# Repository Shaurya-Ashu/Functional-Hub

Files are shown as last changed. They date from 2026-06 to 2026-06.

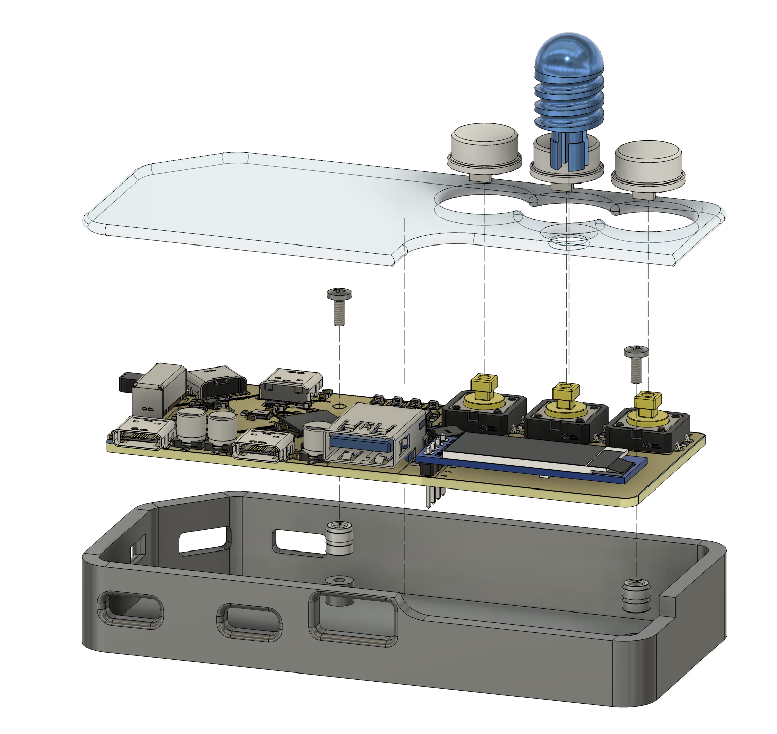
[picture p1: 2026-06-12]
Assembly/Screenshot 2026-06-12 at 9.54.39 PM.png

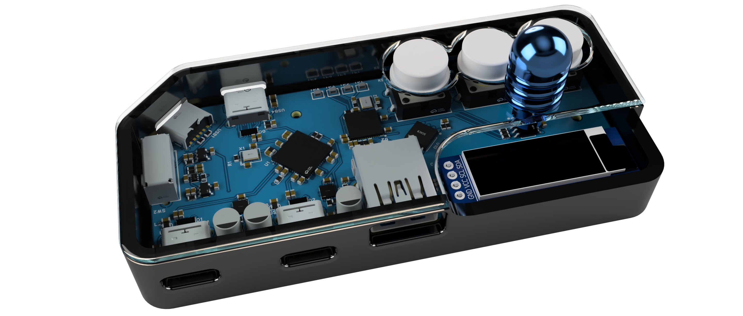
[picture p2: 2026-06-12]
Img/Untitled_2026-Jun-12_02-12-34PM-000_CustomizedView5272772413_png_alpha.png

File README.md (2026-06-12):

# Functional-Hub
It's is a 3.0 USB Hub X Macro Pad.

Yeah its a Fusion dish of some of the most needed things in one , designed by me aka Shaurya a 17 Y/O from India

# Zine

Frame 2

# Why i build it 
I was going through the guided project files when i discover about a guide to build a USB Hub , but its was kinda simple so i thoungh why not build some thing complex . Then i came to this conclusion to build a 3.0 fast (kinda) USB Hub with a in-built Macro Pad .

# Schematics

SCH_Schematic1_1-P1_2026-06-13

So let's begain with the tech talk

I have used TUSB8041RGCT IC from Texas industries comes in a 64-Pin QFN Package, it is a 5Gbps high speed 1x stream & 4x downstream USB hub IC.
It took me a long time to figure out connection and working of this IC , I've spent hours reading the datasheet . It also supports external powered for downstream USBs with Over current detection and auto shut down of downstream ports.
Screenshot 2026-06-13 at 2 13 01 AM

For over current protection, I've used another IC from Texas industries i.e. TPS2561DRCR .
I saw this in one of the datasheet of a high speed USB hub. It allows maximum of 2 A per downstream port.
Screenshot 2026-06-13 at 2 16 48 AM

The four down port are divided as:
--> 2x USB-C
--> 1x USB-A
--> RP2040 (directly connected)

This is a separate IC for ESD protection on every downstream & upstream port .

Upstream port :
Screenshot 2026-06-13 at 2 21 19 AM

Downstream port's :
Screenshot 2026-06-13 at 2 21 02 AM

There is a separate USB-C for powering the downstream ports .I have also added a switch to change between the upstream power source and external power source.
Screenshot 2026-06-13 at 2 25 24 AM

Now the Macro Pad 

The main mcu for this is a RP2040 which is the chepest and most reliable mcu for this application .
It's from our fav company raspberry pi . It requires a separate memory to flash code as it doesn't have one in-built. Also, I have connected the USB interface of RP2040 directly to the fourth downstream port of the USB hub IC.
Screenshot 2026-06-13 at 2 30 04 AM

This macro pad has:
--> 3x Push Button
--> 0.91 OLED 128X32
--> Magnetic Rotary Encoder

Screenshot 2026-06-13 at 2 32 47 AM

# PCB 

It's a 4 layer pcb with top and bottom layers signal and inner layers as ground and power.

The wiring was the most difficult part in this project, I was going through many Dattasheets and read post, but was not able to figure out what was the impedance and proper track width and lenght so, there it's the major flow of my design as it will not provide the maximum speed (5Gbps) but should have better speed than a normal 2.0 USB hub.

Top layer:
Screenshot 2026-06-13 at 2 38 58 AM

Bottom layer:
Screenshot 2026-06-13 at 2 39 19 AM

Inner GND layer:
Screenshot 2026-06-13 at 2 40 05 AM

Inner Power layer:
Screenshot 2026-06-13 at 2 40 42 AM

power one had mulltiple different power line so i simply used traces to connect them while the rest of the macro pad had a common power source so I used a copper fill region there.

# CAD 

I used Fusion 360 stu. License version to create the enclosure for this USB hub.
The base will be a simple 3D printed part with screw holes to properly secure the PCB.
The top will be a custom cut translucent acrylic sheet which will be glued to the bottom case.

Here are some of the rendering of the final product.

Untitled_2026-Jun-12_02-11-34PM-000_CustomizedView20562888345_png_alpha
Untitled_2026-Jun-12_02-12-34PM-000_CustomizedView5272772413_png_alpha
Untitled_2026-Jun-12_02-24-10PM-000_CustomizedView5463506446_png_alpha

# Assembly

Bottom Base

Those are M2 Screw's & the top acrylic sheet will be glued .

# Firmware

It's Claude generator as I am not that good with firmware
It is specifically for RP2040 macro pad configuration

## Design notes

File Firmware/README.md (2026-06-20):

# Functional Hub — RP2040 Macropad Firmware

## Hardware (from schematic)
| Function | RP2040 Pin |
|---|---|
| SW1 (Key 0) | GP6 |
| SW2 (Key 1) | GP7 |
| SW3 (Key 2) | GP8 |
| Encoder A | GP9 |
| Encoder B | GP10 |
| Encoder Button  | GP11 |
| OLED SDA | GP4 |
| OLED SCL | GP5 |
| NeoPixel | GP16 |

---

## Flashing steps

1. **Install CircuitPython 9.x**
   - Hold BOOTSEL on RP2040 → connect USB → drag `adafruit-circuitpython-raspberry_pi_pico-en_US-9.x.x.uf2` onto the `RPI-RP2` drive.
   - Drive reappears as `CIRCUITPY`.

2. **Install libraries**  
   Download the [CircuitPython 9.x library bundle](https://circuitpython.org/libraries) and copy these folders/files into `CIRCUITPY/lib/`:
   ```
   adafruit_hid/
   adafruit_display_text/
   adafruit_displayio_ssd1306.mpy
   adafruit_debouncer.mpy
   neopixel.mpy
   ```

3. **Copy firmware files**  
   Copy all three files to the root of `CIRCUITPY/`:
   ```
   boot.py
   code.py
   keymap.py
   ```
   Eject safely → replug. The device enumerates as a USB HID keyboard.

---

## Usage

### Boot modes
| Condition | Result |
|---|---|
| SW1 NOT held | HID macropad (storage hidden from host) |
| SW1 held at boot | CIRCUITPY drive visible + REPL |

### Layers (cycle with SW3)
| Layer | Name | Colour |
|---|---|---|
| 0 | Media  | Blue |
| 1 | Gaming | Green  |
| 2 | CAD | Amber  |

### Default bindings

**Layer 0 — Media**
| Input | Action |
|---|---|
| SW1 | Mute |
| SW2 | Win+Shift+S (snip)|
| SW3 | Next layer |
| Enc CW | Volume Up |
| Enc CCW | Volume Down |
| Enc Push | Play/Pause |

**Layer 1 — Gaming**
| Input | Action |
|---|---|
| SW1 | Caps Lock (PTT) |
| SW2 | Tab (scoreboard)|
| SW3 | Next layer |
| Enc CW | E (next item)|
| Enc CCW  | Q (prev item)|
| Enc Push | R (reload) |

**Layer 2 — CAD**
| Input | Action |
|---|---|
| SW1 | Ctrl+Z |
| SW2 | Ctrl+Y |
| SW3 | Next layer|
| Enc CW | Zoom In  |
| Enc CCW  | Zoom Out |
| Enc Push | F (fit)  |

---

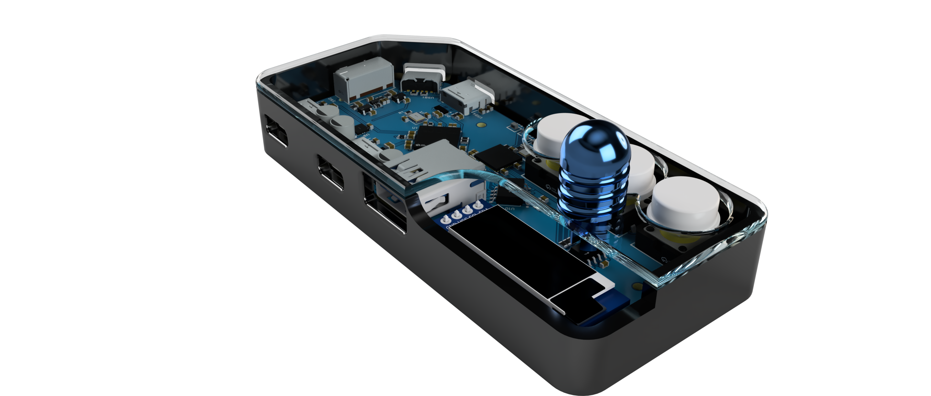
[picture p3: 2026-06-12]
Img/Untitled_2026-Jun-12_02-11-34PM-000_CustomizedView20562888345_png_alpha.png

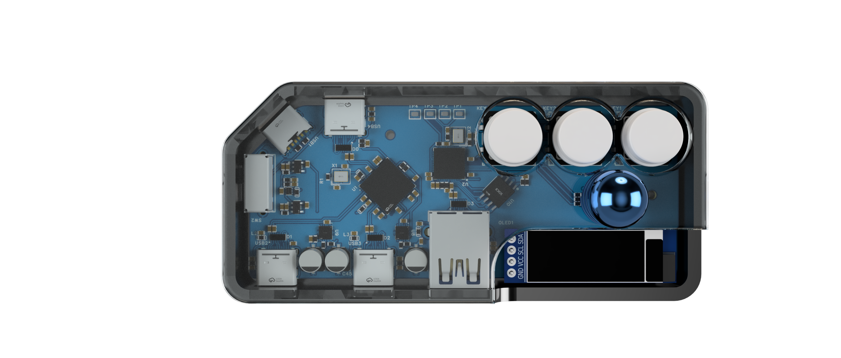
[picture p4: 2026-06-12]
Img/Untitled_2026-Jun-12_02-12-03PM-000_CustomizedView24574289227_png_alpha.png

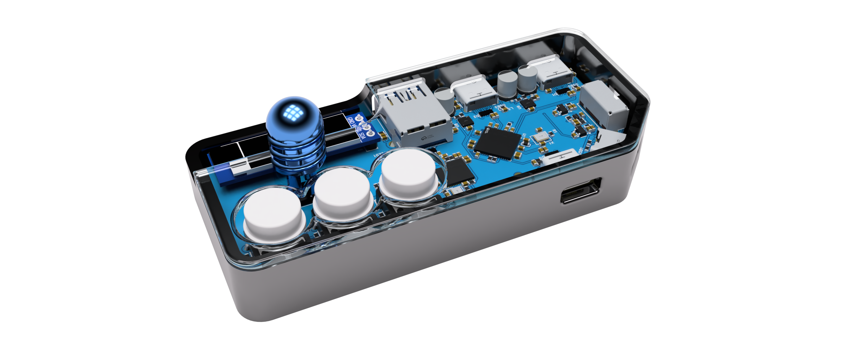
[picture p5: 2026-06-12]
Img/Untitled_2026-Jun-12_02-24-10PM-000_CustomizedView5463506446_png_alpha.png

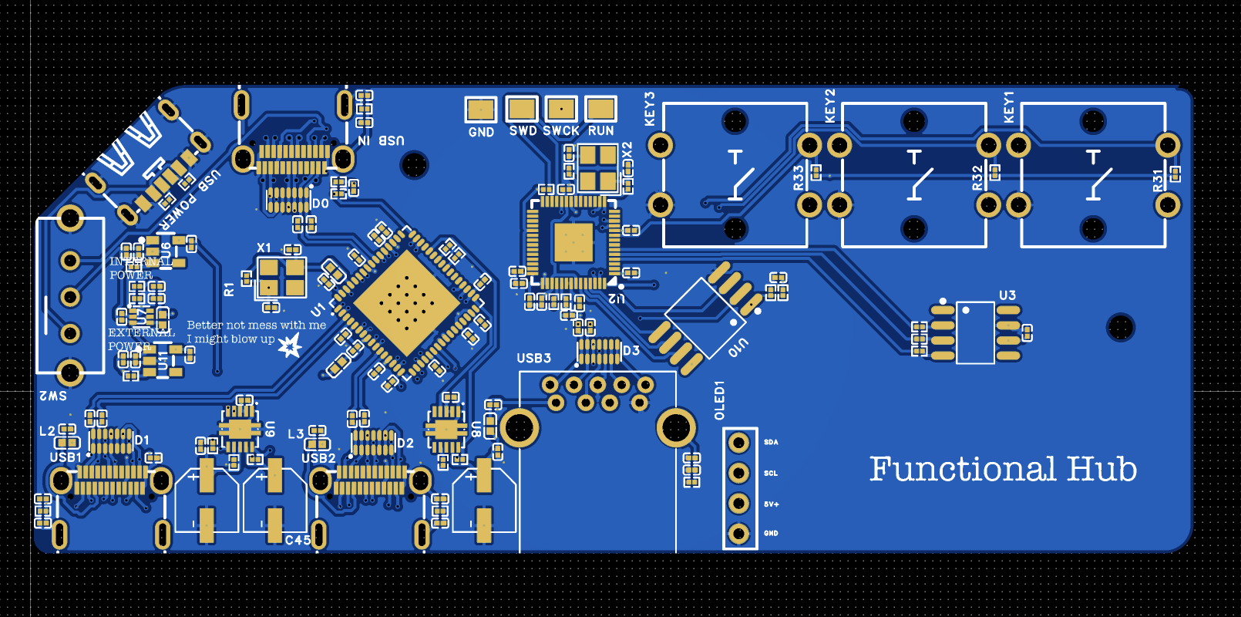
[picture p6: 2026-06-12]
PCB/TOP.png

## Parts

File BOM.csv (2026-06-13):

Item No. | Item | Description | Quantity | Price Per Unit ($) | Total Price ($) | Link
1 | Capacitor 1nF | Ceramic Capacitor 1nF ±10% 50V X7R 0201 | 4 | 0.0018 | 0.18 | https://www.lcsc.com/product-detail/C505464.html
2 | Capacitor 100nF | Ceramic Capacitor 100nF ±10% 16V X5R 0201 | 27 | 0.0029 | 0.29 | https://www.lcsc.com/product-detail/C307380.html
3 | Resistor 100Ω | Thick Film Resistor 100Ω ±1% 50mW 0201 | 2 | 0.0010 | 0.10 | https://www.lcsc.com/product-detail/C77623.html
4 | Resistor 100kΩ | Thick Film Resistor 100kΩ ±1% 50mW 0201 | 1 | 0.0010 | 0.10 | https://www.lcsc.com/product-detail/C106224.html
5 | Capacitor 100nF (2) | Ceramic Capacitor 100nF ±10% 16V X5R 0201 | 18 | 0.0029 | 0.29 | https://www.lcsc.com/product-detail/C307380.html
6 | Resistor 10kΩ | Thick Film Resistor 10kΩ ±5% 50mW 0201 | 12 | 0.0009 | 0.09 | https://www.lcsc.com/product-detail/C138117.html
7 | Capacitor 10uF | Ceramic Capacitor 10uF ±20% 6.3V X5R 0402 | 2 | 0.0187 | 1.87 | https://www.lcsc.com/product-detail/C15525.html
8 | X322512MSB4SI | 12MHz | 1 | 0.1011 | 0.51 | https://www.lcsc.com/product-detail/C9002.html
9 | VZT151M1VTR-0607 | 150uF | 3 | 0.1643 | 0.82 | https://www.lcsc.com/product-detail/C249984.html
10 | Capacitor 18pF | Ceramic Capacitor 18pF ±5% 50V C0G 0201 | 2 | 0.0034 | 0.34 | https://www.lcsc.com/product-detail/C85892.html
11 | Resistor 1kΩ | Thick Film Resistor 1kΩ ±1% 50mW 0201 | 1 | 0.0010 | 0.10 | https://www.lcsc.com/product-detail/C138165.html
12 | Resistor 1MΩ | Thick Film Resistor 1MΩ ±5% 50mW 0201 | 5 | 0.0010 | 0.10 | https://www.lcsc.com/product-detail/C473450.html
13 | Inductor 1uH | Multilayer Inductor 1uH ±20% 450mA 350mΩ 0402 | 1 | 0.0583 | 0.58 | https://www.lcsc.com/product-detail/C531288.html
14 | Capacitor 1uF | Ceramic Capacitor 1uF ±20% 10V X5R 0201 | 5 | 0.0056 | 0.56 | https://www.lcsc.com/product-detail/C170153.html
15 | Capacitor 22uF | Ceramic Capacitor 22uF ±20% 25V X5R 0805 | 2 | 0.1137 | 1.14 | https://www.lcsc.com/product-detail/C602037.html
16 | ABM8-24.000MHZ-B2-T | 24MHz | 1 | 0.3985 | 1.99 | https://www.lcsc.com/product-detail/C596897.html
17 | Resistor 25.5kΩ | Thick Film Resistor 25.5kΩ ±1% 50mW 0201 | 2 | 0.0103 | 0.52 | https://www.lcsc.com/product-detail/C2074563.html
18 | Resistor 27kΩ | Thick Film Resistor 27kΩ ±1% 50mW 0201 | 2 | 0.1194 | 0.60 | https://www.lcsc.com/product-detail/C2074373.html
19 | Resistor 4.7kΩ (A) | Thick Film Resistor 4.7kΩ ±1% 50mW 0201 | 2 | 0.0071 | 0.71 | https://www.lcsc.com/product-detail/C3000902.html
20 | Resistor 4.7kΩ (B) | Thick Film Resistor 4.7kΩ ±1% 50mW 0201 | 3 | 0.0071 | 0.71 | https://www.lcsc.com/product-detail/C3000902.html
21 | Capacitor 4.7uF | Ceramic Capacitor 4.7uF ±20% 6.3V X5R 0201 | 1 | 0.0732 | 0.73 | https://www.lcsc.com/product-detail/C335103.html
22 | Resistor 470Ω | Thick Film Resistor 47Ω ±5% 50mW 0201 | 1 | 0.0017 | 0.01 | https://www.lcsc.com/product-detail/C4058027.html
23 | Resistor 83.3kΩ | Metal Film Resistor 83kΩ ±2% 250mW Through Hole | 1 | 0.9533 | 0.95 | https://www.lcsc.com/product-detail/C3522106.html
24 | Resistor 90.9kΩ | Thick Film Resistor 90.9kΩ ±1% 50mW 0201 | 1 | 0.0432 | 0.43 | https://www.lcsc.com/product-detail/C2078275.html
25 | Tactile Switch | SPST Tactile Switch 12x12mm Through Hole | 3 | 0.1302 | 0.65 | https://www.lcsc.com/product-detail/C84931.html
26 | Ferrite Bead 220Ω | Ferrite Bead 220Ω@100MHz 2.2A 0603 | 5 | 0.0222 | 1.11 | https://www.lcsc.com/product-detail/C88980.html
27 | USB-A Connector | USB-A Receptacle 9-Pin Right Angle Through Hole | 1 | 0.1240 | 0.62 | https://www.lcsc.com/product-detail/C7501850.html
28 | OLED 0.91\" 128x32 |  | 1 | N/A | N/A
29 | RP2040 MCU | Raspberry Pi RP2040 Microcontroller QFN-56 | 1 | N/A | N/A | https://www.lcsc.com/product-detail/C2961140.html
30 | Test Point | SMD Test Point | 4 | 0.2990 | 1.50 | https://www.lcsc.com/product-detail/C5846954.html
31 | Slide Switch | SPDT Slide Switch Through Hole | 1 | 0.1182 | 0.59 | https://www.lcsc.com/product-detail/C136720.html
32 | Magnetic Encoder | TLE5012B 360° Magnetic Angle Sensor SO-8 | 1 | 5.4077 | 5.41 | https://www.lcsc.com/product-detail/C2655225.html
33 | Buck Converter | TLV62568 1A 1.5MHz Step-Down DC-DC Regulator SOT-563 | 1 | 0.2468 | 1.23 | https://www.lcsc.com/product-detail/C398368.html
34 | LDO Regulator 3.3V | TLV700 3.3V 300mA LDO Regulator SOT-23-5 | 2 | 0.1635 | 0.82 | https://www.lcsc.com/product-detail/C2877582.html
35 | ESD Protection | TPD6E05U06 USB ESD Protection Diode USON-14 | 4 | 0.5103 | 2.04 | https://www.lcsc.com/product-detail/C962978.html
36 | Load Switch | TPS2561 2.8A High-Side Power Switch VSON-10 | 2 | 1.0079 | 2.02 | https://www.lcsc.com/product-detail/C140303.html
37 | USB 3.0 Hub IC | TUSB8041 4-Port USB 3.0 Hub Controller VQFN-64 | 1 | 12.2050 | 12.21 | https://www.lcsc.com/product-detail/C702388.html
38 | USB-C Connector (Full) | USB-C 24-Pin SMD Right Angle Receptacle | 3 | 0.6425 | 1.93 | https://www.lcsc.com/product-detail/C381478.html
39 | USB-C Connector (Power) | USB-C 6-Pin SMD Power Connector | 1 | 0.0347 | 0.35 | https://www.lcsc.com/product-detail/C53207798.html
40 | Flash Memory | W25Q128 128Mbit SPI NOR Flash SOIC-8 | 1 | 2.7750 | 27.75 | https://www.lcsc.com/product-detail/C113767.html
41 | PCB | Custom Printed Circuit Board | 1 | 7.00 | 7.00
42 | 3D Printed Parts | 3D Printed Enclosure / Structural Parts | 1 | 5.00 | 5.00
 |  |  |  | GRAND TOTAL | 83.95

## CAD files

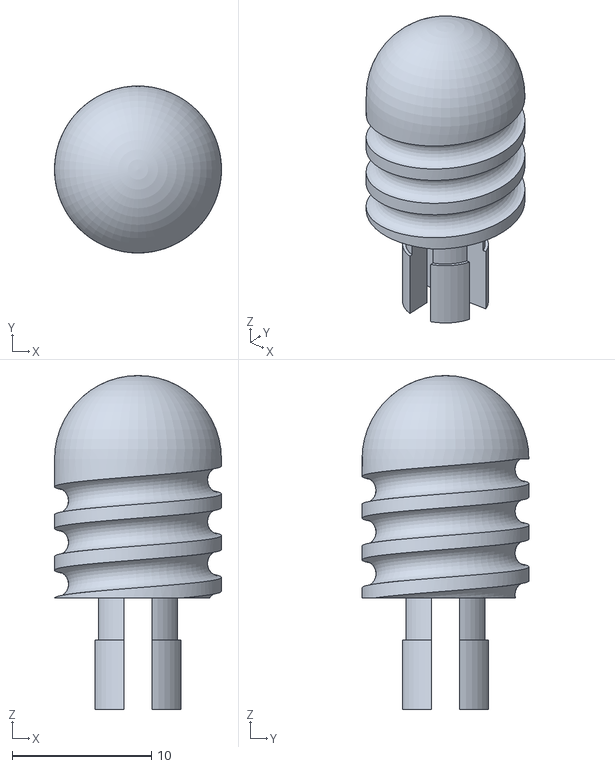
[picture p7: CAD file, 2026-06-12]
CAD/KNOB.stl
12.0 x 12.0 x 24.0

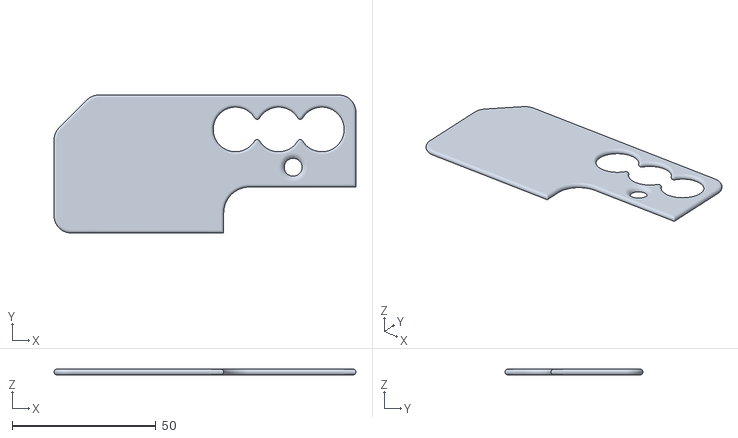
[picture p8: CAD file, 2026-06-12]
CAD/TOP.stl
105.0 x 48.0 x 2.00

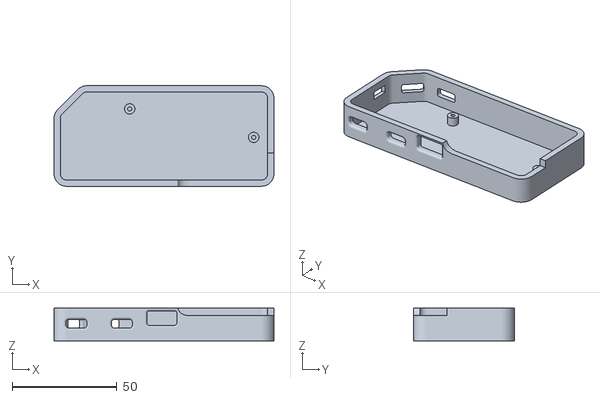
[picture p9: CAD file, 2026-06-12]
CAD/BASE.stl
105.0 x 48.0 x 15.6

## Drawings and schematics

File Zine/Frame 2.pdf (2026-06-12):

# FUNCTIONAL HUB

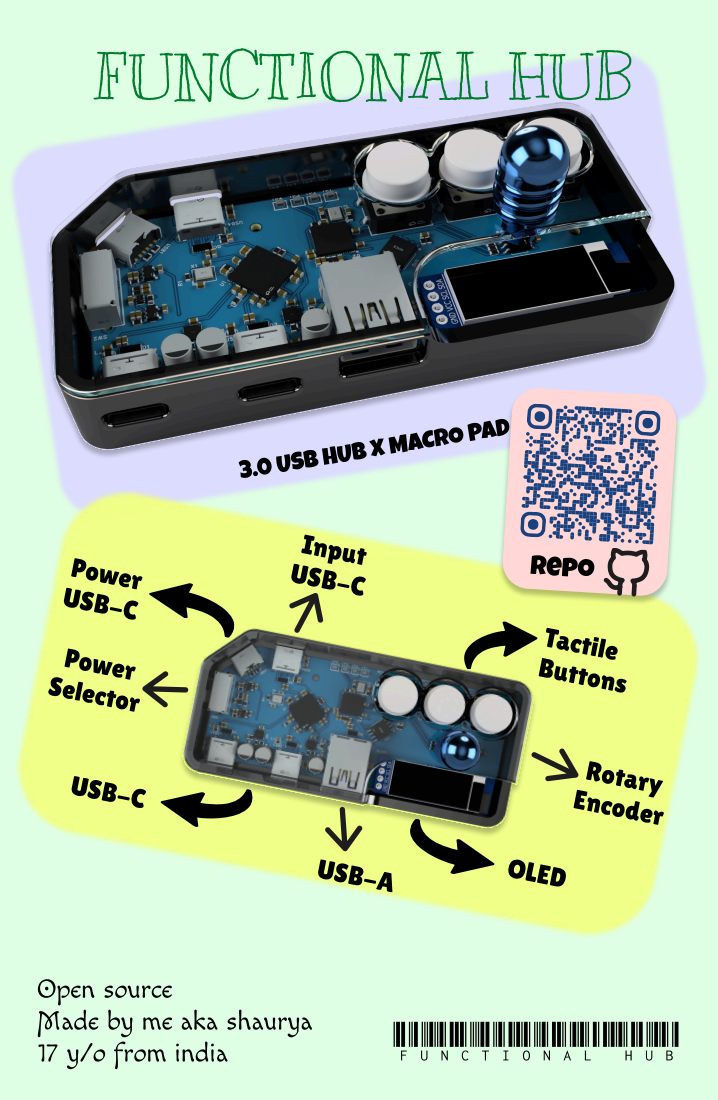
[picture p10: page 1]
Power USB-C; Power Selector; USB-C; Input USB-C; USB-A; Rotary Encoder; OLED; repo; Tactile Buttons; 17 y/o from india; FUNCTIONAL HUB

3.0 USB HUB X MACRO PAD

Open source
Made by me aka shaurya

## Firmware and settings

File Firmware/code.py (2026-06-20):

import time
import board
import busio
import displayio
import terminalio
import digitalio
import rotaryio
import neopixel
import usb_hid

from adafruit_hid.keyboard import Keyboard
from adafruit_hid.keyboard_layout_us import KeyboardLayoutUS
from adafruit_hid.consumer_control import ConsumerControl
from adafruit_debouncer import Debouncer
from adafruit_display_text import label
import adafruit_displayio_ssd1306

import keymap  
kbd = Keyboard(usb_hid.devices)
layout = KeyboardLayoutUS(kbd)
cc = ConsumerControl(usb_hid.devices)


_raw_keys = []
for pin in keymap.KEY_PINS:
    p = digitalio.DigitalInOut(pin)
    p.direction = digitalio.Direction.INPUT
    p.pull = digitalio.Pull.UP
    _raw_keys.append(p)

keys = [Debouncer(p) for p in _raw_keys]


_enc_sw_raw = digitalio.DigitalInOut(keymap.ENCODER_SW)
_enc_sw_raw.direction = digitalio.Direction.INPUT
_enc_sw_raw.pull = digitalio.Pull.UP
enc_sw = Debouncer(_enc_sw_raw)


encoder = rotaryio.IncrementalEncoder(keymap.ENCODER_A, keymap.ENCODER_B)
last_enc_pos = encoder.position


pixels = None
if keymap.NEOPIXEL_PIN is not None:
    pixels = neopixel.NeoPixel(
        keymap.NEOPIXEL_PIN, keymap.NUM_PIXELS, brightness=0.15, auto_write=True
    )

def set_pixel_for_layer(layer_idx):
    if pixels is not None:
        pixels[0] = keymap.LAYER_COLOURS[layer_idx % len(keymap.LAYER_COLOURS)]


displayio.release_displays()

i2c = busio.I2C(scl=keymap.I2C_SCL, sda=keymap.I2C_SDA, frequency=400_000)
display_bus = displayio.I2CDisplay(i2c, device_address=0x3C)
display = adafruit_displayio_ssd1306.SSD1306(
    display_bus, width=keymap.OLED_WIDTH, height=keymap.OLED_HEIGHT
)


main_group = displayio.Group()


lbl_layer = label.Label(
    terminalio.FONT,
    text="",
    color=0xFFFFFF,
    x=2,
    y=8,
    scale=1,
)


lbl_action = label.Label(
    terminalio.FONT,
    text="Ready",
    color=0xFFFFFF,
    x=2,
    y=22,
    scale=1,
)

main_group.append(lbl_layer)
main_group.append(lbl_action)
display.show(main_group)

def update_display(layer_name, action_name):
    lbl_layer.text  = f"[{layer_name}]"
    lbl_action.text = action_name[:20]   
  
current_layer = 0

def get_layer():
    return keymap.LAYERS[current_layer]


def fire(action):
    """
    action tuple: ("label", type, payload)
    Handles key, mod, cc, macro, layer actions.
    """
    global current_layer
    label_str, atype, payload = action

    if atype == "key":
        kbd.press(payload)
        kbd.release_all()

    elif atype == "mod":
        if isinstance(payload, (list, tuple)):
            kbd.press(*payload)
        else:
            kbd.press(payload)
        kbd.release_all()

    elif atype == "cc":
        cc.send(payload)

    elif atype == "macro":
        
        for k in payload:
            kbd.press(k)
            time.sleep(0.05)
            kbd.release_all()
            time.sleep(0.02)

    elif atype == "layer":
        current_layer = payload % len(keymap.LAYERS)
        set_pixel_for_layer(current_layer)

    update_display(get_layer()["name"], label_str)


set_pixel_for_layer(current_layer)
update_display(get_layer()["name"], "Ready")
print("Functional Hub Macropad — ready")


while True:
    layer = get_layer()

    
    for k in keys:
        k.update()
    enc_sw.update()

    
    for idx, k in enumerate(keys):
        if k.fell:   
            action = layer["keys"][idx]
            fire(action)

  
    if enc_sw.fell:
        fire(layer["encoder_sw"])

    
    pos = encoder.position
    delta = pos - last_enc_pos
    last_enc_pos = pos

    if delta > 0:
        for _ in range(abs(delta)):
            fire(layer["encoder_cw"])
    elif delta < 0:
        for _ in range(abs(delta)):
            fire(layer["encoder_ccw"])

    time.sleep(0.005)  

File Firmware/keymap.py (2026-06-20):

import board
import usb_hid
from adafruit_hid.keycode import Keycode
from adafruit_hid.consumer_control_code import ConsumerControlCode


KEY_PINS = [
    board.GP6,  
    board.GP7,  
    board.GP8,  
]

ENCODER_A   = board.GP9
ENCODER_B   = board.GP10
ENCODER_SW  = board.GP11  

I2C_SDA = board.GP4
I2C_SCL = board.GP5

NEOPIXEL_PIN = board.GP16   
NUM_PIXELS   = 1



LAYERS = [
    
    {
        "name": "Media",
        "keys": [
            ("Mute",        "cc",    ConsumerControlCode.MUTE),
            ("Screenshot",  "mod",   (Keycode.GUI, Keycode.SHIFT, Keycode.S)),
            ("Layer →",     "layer", 1),
        ],
        "encoder_cw":  ("Vol+",   "cc", ConsumerControlCode.VOLUME_INCREMENT),
        "encoder_ccw": ("Vol-",   "cc", ConsumerControlCode.VOLUME_DECREMENT),
        "encoder_sw":  ("Play",   "cc", ConsumerControlCode.PLAY_PAUSE),
    },

  
    {
        "name": "Gaming",
        "keys": [
            ("Push-to-Talk", "key",   Keycode.CAPS_LOCK),
            ("Scoreboard",   "key",   Keycode.TAB),
            ("Layer →",      "layer", 2),
        ],
        "encoder_cw":  ("Next weapon", "key", Keycode.E),
        "encoder_ccw": ("Prev weapon", "key", Keycode.Q),
        "encoder_sw":  ("Reload",      "key", Keycode.R),
    },

  
    {
        "name": "CAD",
        "keys": [
            ("Undo",     "mod",   (Keycode.CONTROL, Keycode.Z)),
            ("Redo",     "mod",   (Keycode.CONTROL, Keycode.Y)),
            ("Layer →",  "layer", 0),
        ],
        "encoder_cw":  ("Zoom In",  "key", Keycode.EQUALS),   
        "encoder_ccw": ("Zoom Out", "key", Keycode.MINUS),
        "encoder_sw":  ("Fit View", "key", Keycode.F),
    },
]


OLED_WIDTH  = 128
OLED_HEIGHT = 32    


LAYER_COLOURS = [
    (0,   80, 255),   
    (0,  200,   0),   
    (200, 80,   0),   
]

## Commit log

2026-06-12 add assembly img
2026-06-12 add pcb img
